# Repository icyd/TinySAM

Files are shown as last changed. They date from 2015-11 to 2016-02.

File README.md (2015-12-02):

# TinySam

This development board, is designed to be breadboard-pin compatible taking into
consideration size, easiness of production (using 2-sided pcb), and price.
The microcontroller implement for this board is the [Atmel's ARM Cortex-M0+ SAM D21](http://www.atmel.com/products/microcontrollers/arm/sam-d.aspx?tab=documents).

Image of TinySAM

### Features:

  * 2 16-pins header connectors with 100 mils pitch, with connection to all the
  available pins of the microcontroller, VIN and GND; compatible with the pin
  layout of breadboards.
  * All through-holes for headers have the connection to traces in the right
  layer, in case of hole plating is not possible.
  * 32.786 Khz crystal for Real-time applications.
  * Cortex debug header (SWD).
  * ESD and VBUS protection.
  * Filter for USB connector.
  * RESET button with filter.
  * 2 LEDs interface (power and controlled by the microcontroller).
  * Smart toggle between power supplies (VBUS or VIN).
  * Landing pads for pogo pins (mass production).

### Power supply

The device could be powered using two different supplies: through **USB cable**
directly, of with an external supply of **6.5v MAX** connected to the **VIN pin**.
The device will select between USB and external supply, with preference for the
last one. Also *when a host USB cable is connected an external supply is
required* to power both 'TinySAM' and guest device.

## License

Ideas for the design taking from (attribution):

 * [Atmel's SAM D21 datasheet](http://www.atmel.com/Images/atmel-42129-sam-d20_datasheet.pdf)
 * [Sparkfun's SAMD21 Mini breakboard](https://www.sparkfun.com/products/13664)
 * [Atmel's SAMD21 Xplained Pro Evaluation kit](http://www.atmel.com/tools/ATSAMD21-XPRO.aspx)

<br />This work is licensed under a <a rel="license" href="http://creativecommons.org/licenses/by-nc-sa/4.0/">Creative Commons Attribution-NonCommercial-ShareAlike 4.0 International License</a>.

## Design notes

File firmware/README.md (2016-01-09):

# TinySam
## Firmware

The repository includes some firmware that could be used together with the board.

### Bootloader

Atmel's SAM-BA bootloader could be installed within the microcontroller and the
communication would be possible using either USB CDC driver, UART, or both
interfaces, depending on the firmware file installed on the
microcontroller. When just one interface is used (UART or USB), the application
would start at address 0x1000 (4096 bytes of memory used by the bootloader). If
both interfaces are implemented, the application would start at address 0x2000
(8192 bytes).

The bootloader is located in:

  * Both interfaces: `samd21_sam_ba_both_interfaces.hex`
  * Uart: `samd21_sam_ba_uart.hex`
  * USB: `samd21_sam_ba_usbcdc.hex`

To program the bootloader use `program_bootloader.sh` script included. Used
 ```./program_bootloader.sh --help``` to see the usage of the script.

To program the bootloader into the device a debugger/programmer tool is
necessary, and `OpenOCD` needs to be installed.

Once the bootloader is programmed, then you can communicate with it if:

  * There is no application programmed in the flash memory of the device.
  * When the device pin PA15 (24th pin of the device and the 8th pin of the
    connector J2 in the development board) is pulled down during
    microcontroller's reset.

In order to communicate with the bootloader, an application is needed. For
example, following could be used:
  * [Atmel SAM-BA In-system Programmer v2.15](http://www.atmel.com/tools/atmelsam-bain-systemprogrammer.aspx)
  * [BOSSA-arduino](https://github.com/shumatech/BOSSA/tree/arduino)

Is important to remember that you need to tell this application which is the
starting address for your device (either 0x1000 or 0x2000).

### Example: Blink test

Once bootloader is installed, an application could be programmer within the
flash memory on the device, in this case an application that blink the user led
on the development board. The source files are available with the repository in
case some modification is required (change output pin, change delay, etc).

If both communication interfaces are implemented, modify the *ROM* starting
address (to 0x2000) in the `samd21g18a_flash.ld` file.

To program the example application to the device just connect the development
port to the USB port and run `make install` (**NOTE: BOSSA-arduino is
required**)

****************************************************************************
Firmware Copyright (C):
    2015 - Alberto Vazquez aka IcyD

        This program is free software: you can redistribute it and/or modify
    it under the terms of the GNU General Public License as published by
    the Free Software Foundation, either version 2 of the License, or
    (at your option) any later version.

        This program is distributed in the hope that it will be useful,
    but WITHOUT ANY WARRANTY; without even the implied warranty of
    MERCHANTABILITY or FITNESS FOR A PARTICULAR PURPOSE.  See the
    GNU General Public License for more details.

        You should have received a copy of the GNU General Public License
    along with this program.  If not, see <http://www.gnu.org/licenses/>.

****************************************************************************

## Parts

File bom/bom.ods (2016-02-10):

RefDes | Name | Value | Quantity |  | Unit. Price | Price p/10 | Price p/25 | Price p/50 | Price p/100
C1, C2, C5, C6, C8 | CAP_0805 | 100n | 5 | 15 | 0.1000 | 0.0360 |  |  | 0.0165 | 0.18 | 20 | 0.72
C3 | CAP_0805 | 1u | 1 | 3 | 0.1000 | 0.0660 |  |  | 0.0468 | 0.066 | 10 | 0.66
C4, C11, C12 | CAP_0805 | 10u | 3 | 9 | 0.2500 | 0.2060 | 0.0472 |  |  | 0.618 | 25 | 1.18
C7 | CAP_0805 | 4.7n | 1 | 3 | 0.1000 | 0.0470 |  |  |  | 0.047 | 10 | 0.47
C9, C10 | CAP_0603 | 18p | 2 | 6 | 0.1000 | 0.0340 |  | 0.0182 | 0.0154 | 0.068 | 10 | 0.34
D1, D2 | LHR974 |  | 2 | 6 | 0.2600 | 0.2070 | 0.1792 |  |  | 0.52 | 4 | 0.828
F1 | 0ZCH0050FF2G |  | 1 | 3 | 0.12 | 0.107 | 0.0992 |  |  | 0.107 | 10 | 1.07
J1 | USB-10118192-0001LF |  | 1 | 3 | 0.46 | 0.433 |  |  |  | 0.46 | 2 | 0.92
J2, J4 | 1-644456-6 |  | 2 | 6
J3 | 87758-10 |  | 1 | 3 | 0.4800 | 0.4500 |  | 0.3600 |  | 0.48 | 2 | 0.96
L1 | IND_0805 | MH2029 | 1 | 3 | 0.1000 | 0.0620 | 0.0568 | 0.0510 | 0.0375 | 0.062 | 0 | 0
Q1 | 2N7002 |  | 1 | 3 | 0.1400 | 0.1280 |  |  | 0.0700 | 0.128 | 10 | 1.28
Q2 | IRLML6402 |  | 1 | 3 | 0.3900 | 0.2160 | 0.1836 | 0.1584 | 0.1333 | 0.216 | 10 | 2.16
R1, R2, R8 | RES_0805 | 330 | 3 | 9 | 0.0770 |  |  | 0.0414 |  | 0.231 | 10 | 0.77
R3 | RES_0805 | 1M | 1 | 3 | 0.0770 |  |  | 0.0414 |  | 0.077 | 0 | 0
R4, R5, R7, R9 | RES_0805 | 100k | 4 | 12 | 0.0770 |  |  | 0.0414 |  | 0.308 | 10 | 0.77
R6, R10 | RES_0805 | 39 | 2 | 6 | 0.0770 |  |  | 0.0414 |  | 0.154 | 15 | 1.155
S1 | SPSTNO_1437566 |  | 1 | 3 | 0.2200 |  | 0.1920 | 0.1720 | 0.1520 | 0.22 | 2 | 0.44
U1 | IP4220CZ6 |  | 1 | 3 | 0.4200 | 0.3390 |  |  | 0.2310 | 0.42 | 5 | 2.1
U2 | ATSAMD21G18A-AU |  | 1 | 3 | 5.3900 | 4.8130 | 4.3316 |  | 3.9465 | 5.39 | 4 | 21.56
U3 | AP2114H-3.3 |  | 1 | 3 | 0.36 | 0.293 |  |  |  | 0.36 | 6 | 2.16
U4 | 74AHCT1G125GV |  | 1 | 3 | 0.25 | 0.205 |  |  |  | 0.25 | 6 | 1.5
Y1 | ABS25 |  | 1 | 3 | 0.3800 | 0.3160 |  | 0.2830 | 0.2520 | 0.38 | 6 | 2.28
 | 3230-10-0103-00 |  |  |  | 1.1300 |  |  |  |  |  | 3 | 3.39
 | ME10G-5-ND (https://www.digikey.com/product-detail/en/3756%2F10%20100/ME10G-5-ND/5308219) |  |  |  | 2.8900 |  |  |  |  |  | 1 | 2.89
 |  |  |  |  |  |  |  |  |  | 10.742 |  | 49.603

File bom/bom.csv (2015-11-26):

# | RefDes | Name | Value | Quantity
1 | C1, C2, C5, C7, C8 | CAP_0805 | 100n | 5
2 | C3 | CAP_0805 | 1u | 1
3 | C4, C11, C12 | CAP_0805 | 10u | 3
4 | C6 | CAP_0805 | 4.7n | 1
5 | C9, C10 | CAP_0603 | 18p | 2
6 | D1, D2 | LHR974 |  | 2
7 | F1 | 0ZCH0050FF2G |  | 1
8 | J1 | USB-10118192-0001LF |  | 1
9 | J2, J4 | 1-644456-6 |  | 2
10 | J3 | 87758-10 |  | 1
11 | L1 | IND_0805 | MH2029 | 1
12 | Q1 | 2N7002 |  | 1
13 | Q2 | IRLML6402 |  | 1
14 | R1, R2, R8 | RES_0805 | 330 | 3
15 | R3 | RES_0805 | 1M | 1
16 | R4, R5, R7, R9 | RES_0805 | 100k | 4
17 | R6, R10 | RES_0805 | 39 | 2
18 | S1 | SPSTNO_1437566 |  | 1
19 | U1 | IP4220CZ6 |  | 1
20 | U2 | ATSAMD21G18A-AU |  | 1
21 | U3 | AP2114H-3.3 |  | 1
22 | U4 | 74AHCT1G125GV |  | 1
23 | Y1 | 9HT7 |  | 1

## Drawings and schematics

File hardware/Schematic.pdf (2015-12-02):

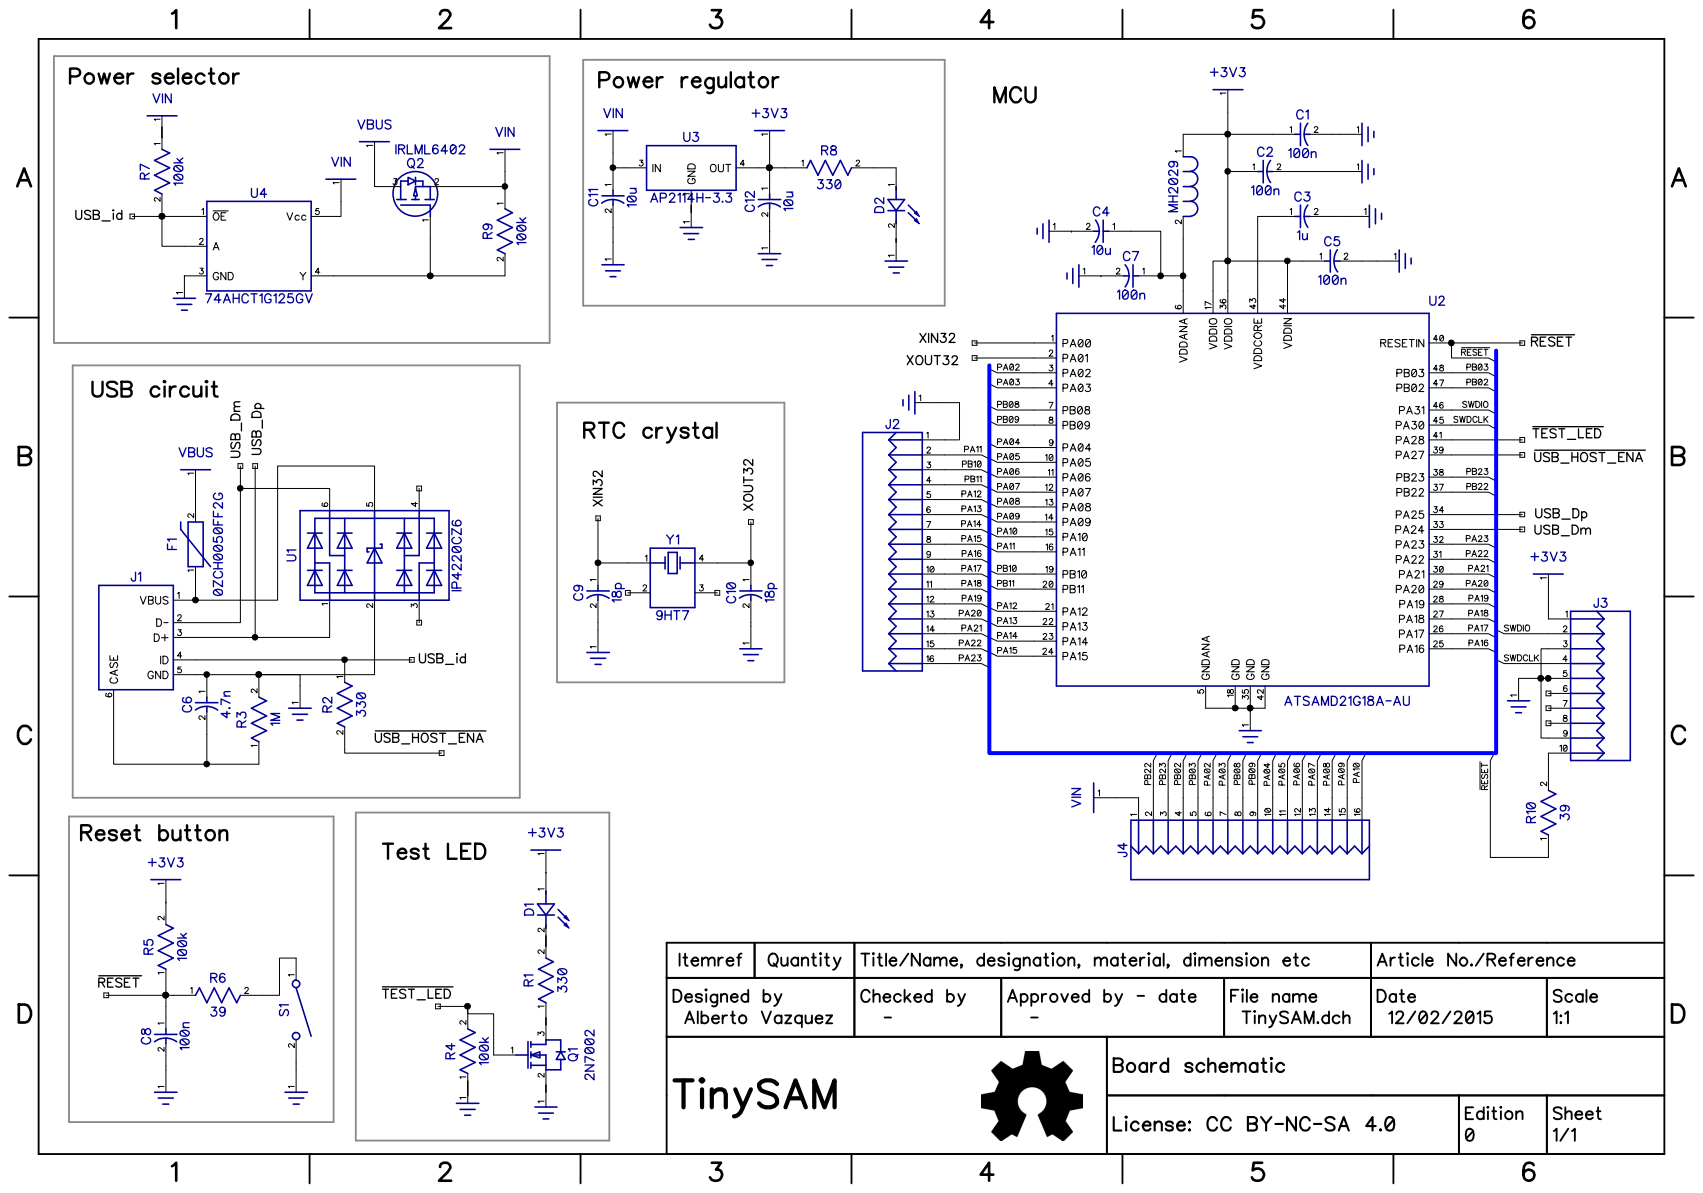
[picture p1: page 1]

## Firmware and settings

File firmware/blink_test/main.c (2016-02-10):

#include "sam.h"

#define LED0 PORT_PA28;

volatile uint32_t SysTickCnt;

void SysTick_Handler (void);
void Delay (uint32_t tick);

int main(void)
{
	SystemInit(); // Initialize the SAM system
	SysTick_Config (SystemCoreClock / 1000 - 1);

	// Configure LED0 as output
	REG_PORT_DIRSET0 = LED0;

	while (1)
	{
		REG_PORT_OUTSET0 = LED0;
		Delay(800);
		REG_PORT_OUTCLR0 = LED0;
		Delay(100);
	}
}

void SysTick_Handler (void)
{
	SysTickCnt++;
}

void Delay (uint32_t tick)
{
	uint32_t systickcnt;

	systickcnt = SysTickCnt;
	while ((SysTickCnt - systickcnt) < tick);
}

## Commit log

2015-11-24 Added some 3D models
    [BOM.csv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]
2015-11-24 Added BOM
    [bom.ods]
2015-11-25 Crystal Changed
    from ABS25 to 9HT7
    [BOM.ods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]
2015-11-26 Added datasheets, and organize folders
    [BOM.ods, bom.csv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]
2015-11-26 Revert "Added datasheets, and organize folders"
    This reverts commit 09b9951d9d93e3803d2262e86bec1c370aab852c.
    [BOM.ods, bom.csv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]
2015-11-26 Revert "Revert "Added datasheets, and organize folders""
    This reverts commit a865ea69bc3c374ed2f3560b6f849d1e53b6a9c7.
    [BOM.ods, bom.csv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]
2015-11-26 Fixed pads for pogo pins (used for mass production)
    [Bottom.gbr, BottomSilk.gbr, Through.drl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]
2015-11-28 Review of repo
    [BOM.csv, BOM.ods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]
2015-11-28 Review of repo 2
    [bom.ods]
2015-12-02 Correction of error on PCB
2015-12-02 Updated Gerber files
    [Bottom.gbr, Through.drl, Top.gbr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]
2015-12-02 Updated pcb
2015-12-02 Updated Schematic and README
2015-12-04 Updated gerbers, and upgrade throung hole components' pads
    [Bottom.gbr, BottomMask.gbr, BottomPaste.gbr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]
2015-12-04 Updated cortex header
    [BottomMask.gbr, BottomSilk.gbr, Through.drl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]
2015-12-27 Changed footprint for 74AHC1G125 to obtain better fitting with the component
    [Bottom.gbr, BottomMask.gbr, BottomSilk.gbr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]
2016-01-09 Added firmware
    [Bottom.gbr, BottomMask.gbr, BottomSilk.gbr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]
2016-01-09 Regenerated gerber
    [Board.gbr, BoardOutline.gbr, Bottom.gbr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]
2016-02-10 Update 2016-02-10
    [bom.ods, samd21.cfg]
